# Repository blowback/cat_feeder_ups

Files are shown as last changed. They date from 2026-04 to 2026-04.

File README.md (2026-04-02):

# UPS for SureFeed Microchip Pet Feeder Connect

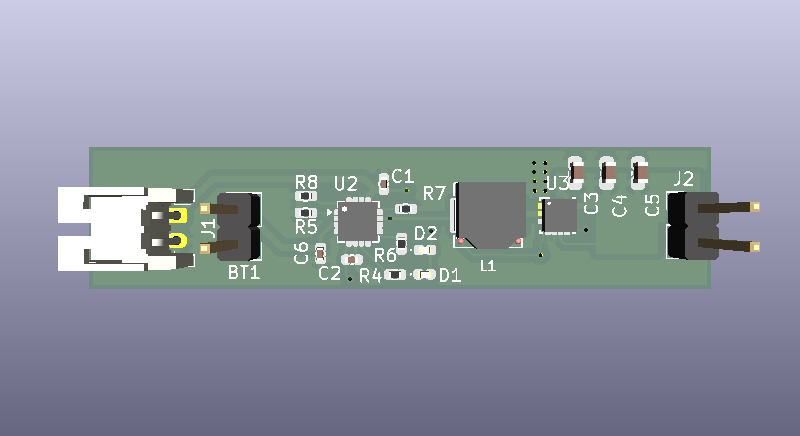
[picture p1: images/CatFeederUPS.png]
cat feeder PCB front

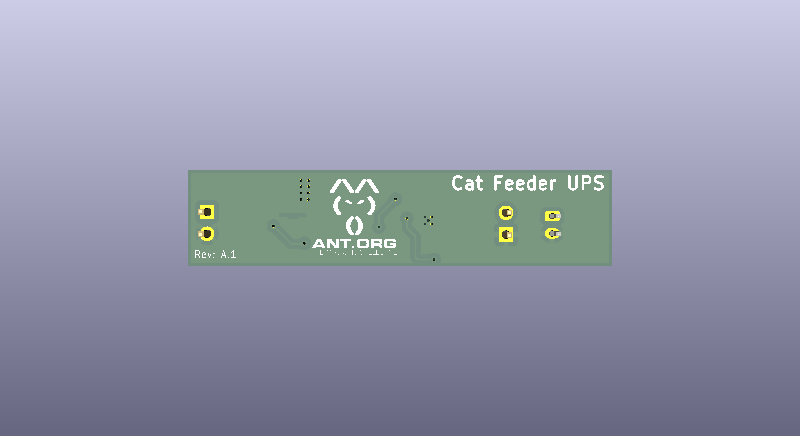
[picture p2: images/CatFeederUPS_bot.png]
cat feeder PCB back


The feeder takes 4 'C' cell batteries. I have 7 feeders. Alkaline batteries 
get expensive real fast and murder the planet, and NiMH cells take an age to 
charge - you spend your whole life swapping batteries in and out of the charger.

The plan: build a miniature UPS that fits inside one of the 2xC-cell battery compartments,
and use it to maintain a 26650 LiPo in the other. Each feeder will be essentially 
mains powered (via a USB adaptor) most of the time: in the event of a power outage 
it will fail over to the battery, which should be sufficient to run it for a couple 
of weeks if necessary.

The other beauty of this approach: the battery has the capacity to handle the current 
draw (inrush and steady-state) when the motor is operating.

## Power consumption analysis

NiCad C cells are nominally 1.2V, so the pack is 4.8V nominal. At 5000mAh rated 
(let's be realistic and call it 2500mAh) and a two-week runtime, we can work out the average current draw:

Energy budget per feeder:

Pack energy: 4.8V × 2.5Ah = 12 Wh realistic
Runtime: 14 days = 336 hours
Average power: 12 Wh / 336 h ≈ 36 mW average
Average current at 4.8V: ≈ 7.5 mA average

**Average** current during motor operation was measured at 250 mA (cheap-ass bench PSU) - 
the peak current is probably 5x that.

## Physical constraints

A standard C cell is:

Diameter: 26.2mm
Length: 50.0mm

Each "slot" holds 2 × C cells stacked = 100mm long × 26.2mm diameter. 

With two slots side by side we have a compartment roughly 100mm deep × ~60mm wide × ~30mm tall (the slots sit in a tray).

### The slot geometry, precisely:

26 mm diameter circular cross-section (C-cell slot)
The usable PCB width isn't 26 mm — it's the chord of that circle at whatever depth the PCB sits. 
If the PCB sits centrally, the usable rectangle inscribed in a 26 mm circle is about 
22 mm wide × 22 mm tall, but since the slot is deep (100 mm) and we're filling it lengthwise, 
we treat the cross-section as a constraint on width only. Realistically 22 mm safe width, 
with the PCB sitting in the bottom of the cylindrical channel.

Length: 90 mm available (100 mm slot minus ~10 mm for wiring clearance to the cell)
Height (component clearance above PCB): roughly 8–10 mm before we hit the slot wall curvature

So we can't afford any big electrolytics or inductors.

## LiPo backup capacity in one C-cell slot:

A single-cell LiPo fits in one C-cell bay (≤26mm diameter, ≤100mm long) — 
cylindrical 26650 LiPo cells are 26mm × 65mm, giving around 4000–5000 mAh at 3.7V nominal = ~15–18 Wh. 

That's actually more energy than the current NiCadx! 

A flat pouch LiPo of similar volume would also work and might be easier to source (e.g. a 103450 or similar).

At 36mW average draw, a 5000mAh/3.7V LiPo = 18.5 Wh → 18.5 Wh ÷ 0.036 W ≈ 514 hours ≈ 21 days of backup. Nice.

Cat biscuits will have run out long before that!

## Proposed architecture

- a LiPo charge controller with "power path" management so that we can use the battery's capacity to absorb motor current demandss
- a boost convertor to boost the LiPo up to 5v. 

## Device selection 

After many, many false starts:

 - BQ24079  for the LiPo controller
 - TPS61235P boost convertor - fixed 5.1v output  and very minimal component controller
 - SPM5020T-1R0M inductor from TDK: nice and compact: 5x2mm, 11A Isat. 

 Those packages are all quite fiddly, and we'll prolly have to go to 0402 for the discretes. 
Maybe time to experiment with having a boardhouse stuff the board!  I'm thinking JLCB...

## JLPCB substitutions

- L1: was C408536 now C695604
- U2: was unspecified! now C140287 (has no SYSOFF pin, but is same package with a NC pad so no schematic/pcb change)
- J1: was C173752 - shouldn't be in BOM (is thru-hole)
- D2: was C2286 (RED) but we want GREEN so -> C12624
- R4, R6: wrong part, need 1.5k 0402 -> C114759
- R5: wrong part, need 10k 0402 -> C60490
- R7: wrong part, need 1.18k -> C3016052
- R8: wrong part, need 1.13k -> C453521

## JLPCB substitutions (2)

Gah, LED footprints are 0402 but the LCSC part numbers are for 0603!

- D1: (RED) -> C130719
- D2: (GREEN) -> C74338
- R8: was C453521 but JLPCB no-stocky, switching forC67014

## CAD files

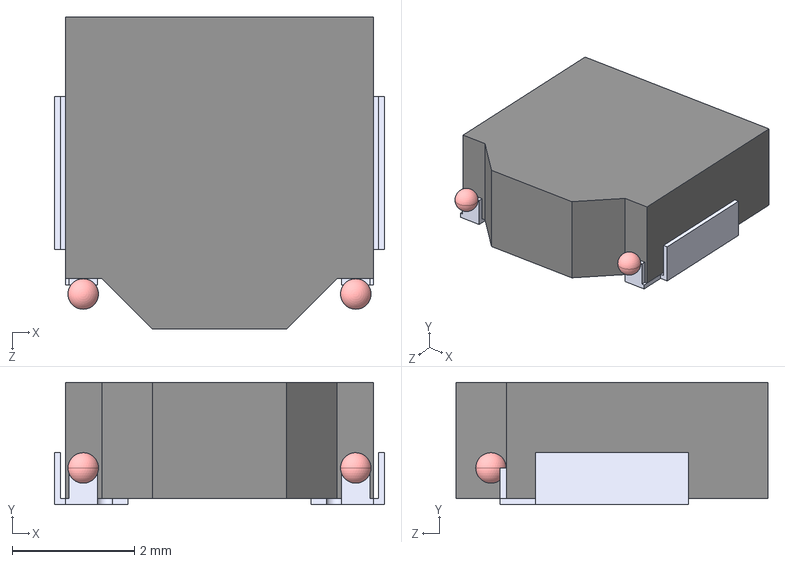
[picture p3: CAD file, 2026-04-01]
Downloads/SPM5020T-1R0M-LR/SPM5020T-1R0M-LR.step
5.40 x 2.00 x 5.10 mm

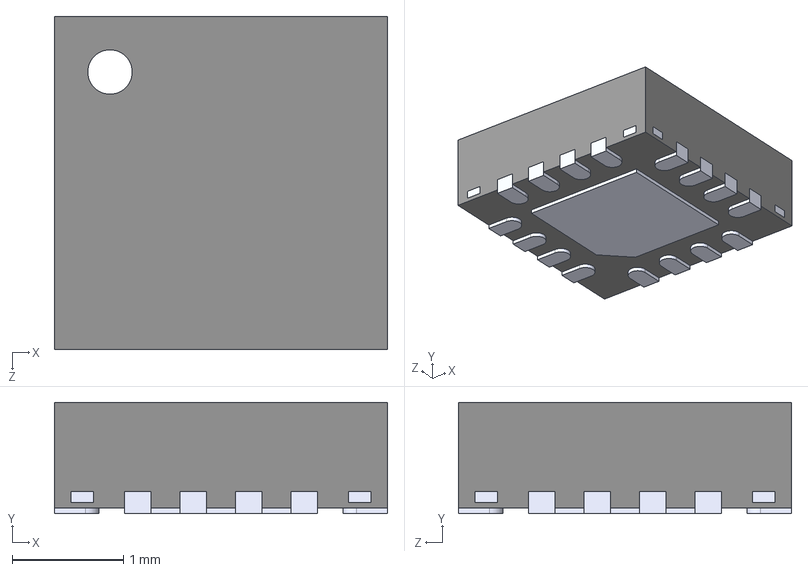
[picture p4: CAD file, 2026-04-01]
Downloads/BQ24079RGTR.STEP
3.00 x 1.00 x 3.00 mm

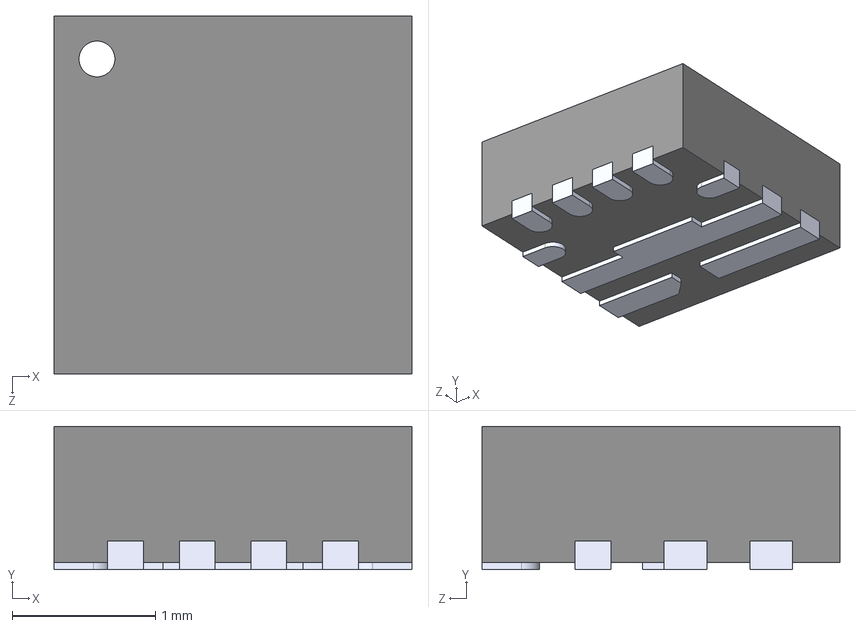
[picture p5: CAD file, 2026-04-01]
Downloads/TPS61235PRWLR/TPS61235PRWLR.step
2.50 x 1.00 x 2.50 mm

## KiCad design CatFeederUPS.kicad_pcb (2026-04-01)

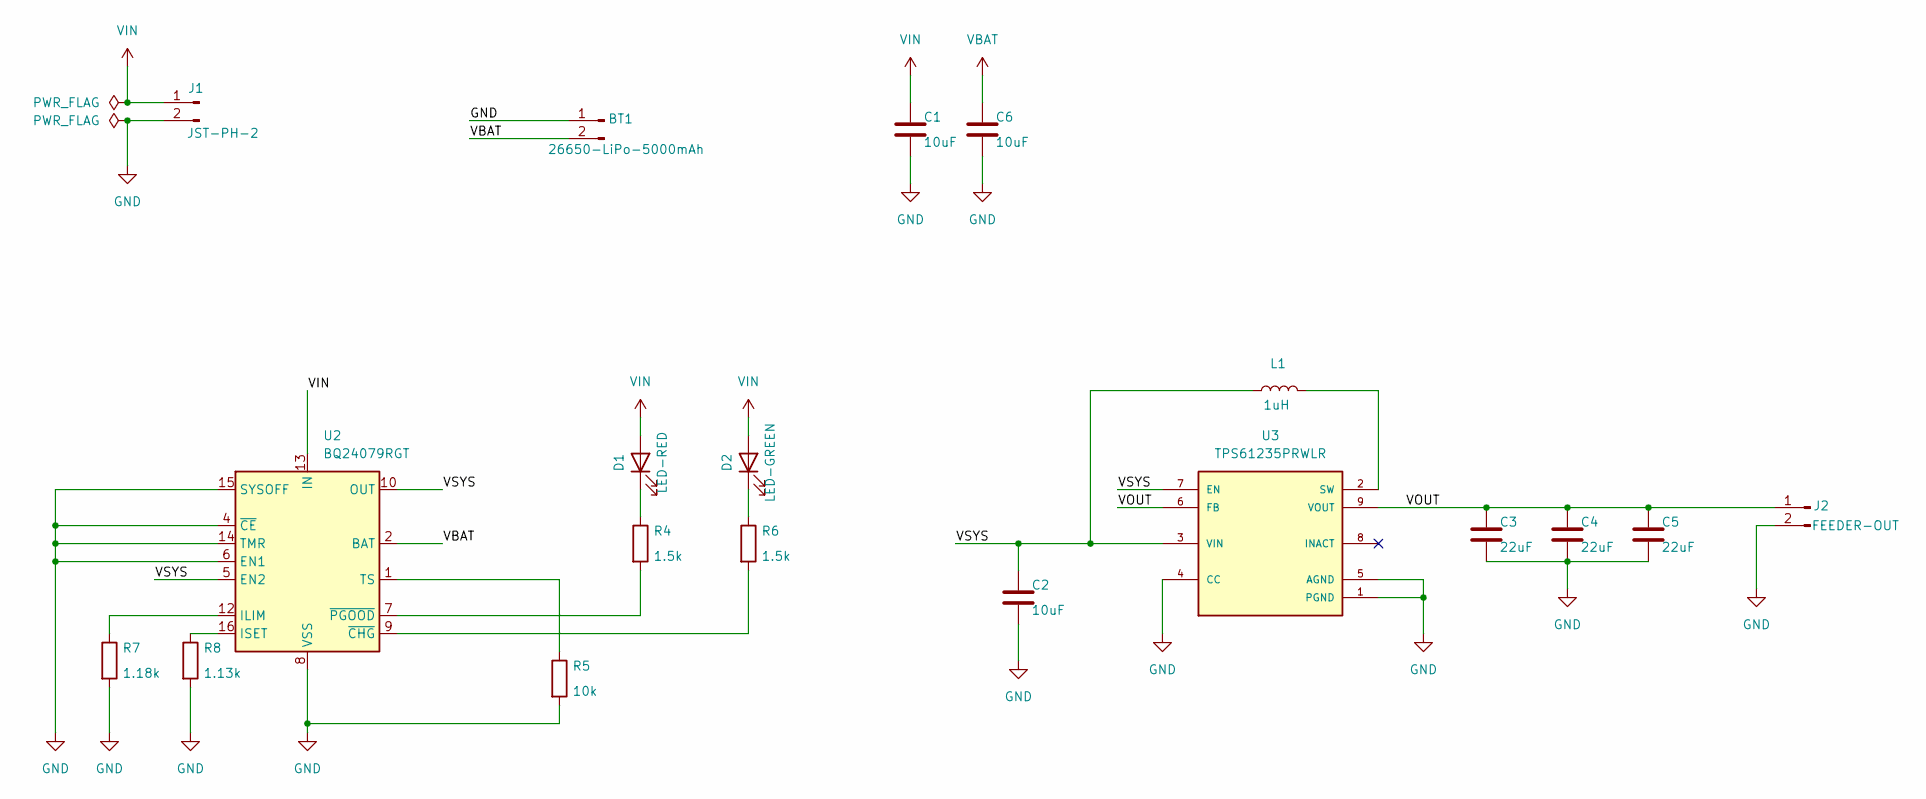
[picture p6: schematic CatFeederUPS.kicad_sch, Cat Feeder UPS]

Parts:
BT1: 26650-LiPo-5000mAh; PinHeader_1x02_P2.54mm_Vertical
C1, C6: 10uF; C_0402_1005Metric; Voltage 10V; LCSC C15525
C2: 10uF; C_0402_1005Metric; Voltage 6.3V; LCSC C15525
C3, C4, C5: 22uF; C_0603_1608Metric; Voltage 10V; LCSC C59461
D1: LED-RED; LED_0402_1005Metric; LCSC C130719
D2: LED-GREEN; LED_0402_1005Metric; LCSC C74338
J1: JST-PH-2; JST_PH_S2B-PH-K_1x02_P2.00mm_Horizontal
J2: FEEDER-OUT; PinHeader_1x02_P2.54mm_Vertical
L1: 1uH; IND_SPM5020T-1R0M-LR; LCSC C695604
R4, R6: 1.5k; R_0402_1005Metric; LCSC C114759
R5: 10k; R_0402_1005Metric; LCSC C60490
R7: 1.18k; R_0402_1005Metric; LCSC C3016052
R8: 1.13k; R_0402_1005Metric; LCSC C67014
U2: BQ24079RGT; VQFN-16-1EP_3x3mm_P0.5mm_EP1.6x1.6mm; LCSC C140287
U3: TPS61235PRWLR; CONV_TPS61235PRWLR; DigiKey_Part_Number 296-47376-1-ND

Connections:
/VOUT: C3.1, C4.1, C5.1, J2.1, U3.6 (FB), U3.9 (VOUT)
/VSYS: C2.1, L1.1, U2.5 (EN2), U2.10 (OUT), U2.11 (OUT), U3.3 (VIN), U3.7 (EN)
GND: BT1.1, C1.2, C2.2, C3.2, C4.2, C5.2, C6.2, J1.2, J2.2, R5.2, R7.2, R8.2, U2.4 (~CE), U2.6 (EN1), U2.8 (VSS), U2.14 (TMR), U2.15 (SYSOFF), U2.17 (VSS), U3.1 (PGND), U3.4 (CC), U3.5 (AGND)
unnamed: D1.1 (K), R4.1
unnamed: D2.1 (K), R6.1
unnamed: R7.1, U2.12 (ILIM)
unnamed: R8.1, U2.16 (ISET)
unnamed: R5.1, U2.1 (TS)
unnamed: R6.2, U2.9 (~CHG)
unnamed: R4.2, U2.7 (~PGOOD)
unnamed: L1.2, U3.2 (SW)
VBAT: BT1.2, C6.1, U2.2 (BAT), U2.3 (BAT)
VIN: C1.1, D1.2 (A), D2.2 (A), J1.1, U2.13 (IN)

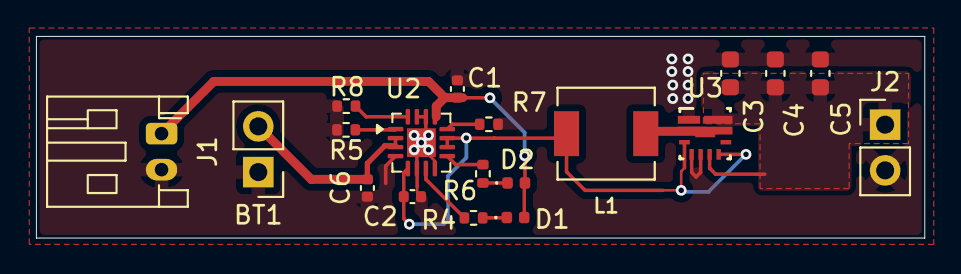
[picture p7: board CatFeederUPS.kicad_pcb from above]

Board: 2 copper layers, 49.4 x 11.2 mm, 19 parts (0 on the bottom side), 13 nets.

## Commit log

2026-04-01 first commit, schematic captured
    [CatFeederUPS.kicad_pcb, CatFeederUPS.kicad_sch, SPM5020T-1R0M-LR.STEP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]
2026-04-01 Basic layout done, but...
    There are a lot of problems with the TPW21635P footprint. It's got a
    gigantic pad 2 (SW) that's a weird T-shape, and both the SnapEDA and
    Ultra Librarian footprints represent this as a "polygon" overlaid over
    a "pad", which causes DRC to complain bitterly about both electrical
    overlap and soldermask overlap, which I cannot fix with board setup,
    design rules exceptions etc. etc.
    So I had to resort to editing the footprint: I selected the pad, clicked
    "edit pad as geometry shapes" or something in the right-click context
    menu, selected both the pad and the polygon, and hit ctrl-e, then saved
    it back to the library.
    This has fixed the DRC complaints, hopefully I hav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
    [CatFeederUPS.kicad_pcb, CatFeederUPS.kicad_sch]
2026-04-01 pcb layout complete
    [BQ24079RGTR.STEP, CatFeederUPS.kicad_pcb]
2026-04-01 squish board
    [CatFeederUPS.kicad_pcb]
2026-04-01 throw some graphics on there
    [CatFeederUPS.kicad_pcb]
2026-04-01 fix LCSC part numbers, and the goddam TPS61235 footprint **again**
    [CatFeederUPS.kicad_pcb, CatFeederUPS.kicad_sch]
2026-04-01 a couple more component swaps, and away into production we go!
    [CatFeederUPS.kicad_pcb, CatFeederUPS.kicad_sch]
